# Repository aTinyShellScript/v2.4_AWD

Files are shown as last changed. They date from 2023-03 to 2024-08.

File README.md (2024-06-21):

# WTF Is This?

An AWD Mod for the Voron v2.4.

## Getting Started

Take a look at the [Sourcing](https://docs.atinyshellscript.com/sourcing/) page to see what you need.

## Issues

Best to report issues directly to @aTinyShellScript in the Armchair Heavy Industries discord. You can also open a GitHub issue here.

## Mods

Put your mod in it's own folder under /UserMods, include a readme.md, and submit a PR.

## Website

Documentation and Assembly Info has been moved to: https://docs.atinyshellscript.com/

## Thanks

[KayosMaker](https://github.com/KayosMaker) whose idea for printed aligners I have shameless borrowed.

[scheini79](https://github.com/scheini79) who made the DoubleT Pin mid-body STL.

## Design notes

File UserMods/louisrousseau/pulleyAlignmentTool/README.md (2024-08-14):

# Pulley Alignment Tool

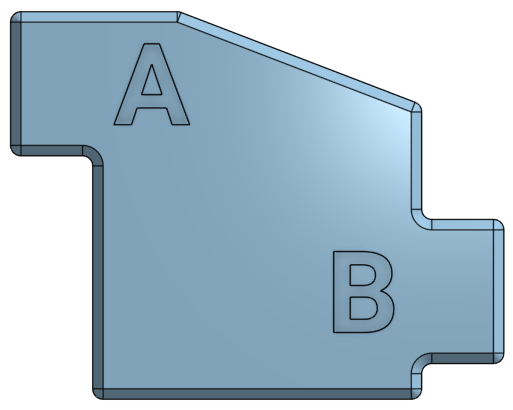
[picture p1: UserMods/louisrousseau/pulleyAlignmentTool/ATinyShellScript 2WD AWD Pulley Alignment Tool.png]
Pulley Alignment Tool


The GT20 pulley height adjustment on the A/B stepper shafts doesn't match the Voron tool or manual diagrams which are referenced on the stepper housing and stock printed motor mounts.

This little tool lets you align the toothed pulleys on your A/B steppers using the face touching the extrusions; doing it this way works around any differences in metal plate thickness.

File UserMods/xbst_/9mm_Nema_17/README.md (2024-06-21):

# AWD 9mm Nema 17 Voron 2.4 Mod
I heard you like mods. So I made a mod of [Chairman Meow's 9mm mod](https://github.com/aTinyShellScript/v2.4_AWD/tree/printy_9mm_mod/Mods/NEMA17_9mm_Belts) of [ATSS's AWD V2.4 mod](https://github.com/aTinyShellScript/v2.4_AWD).

## Picture

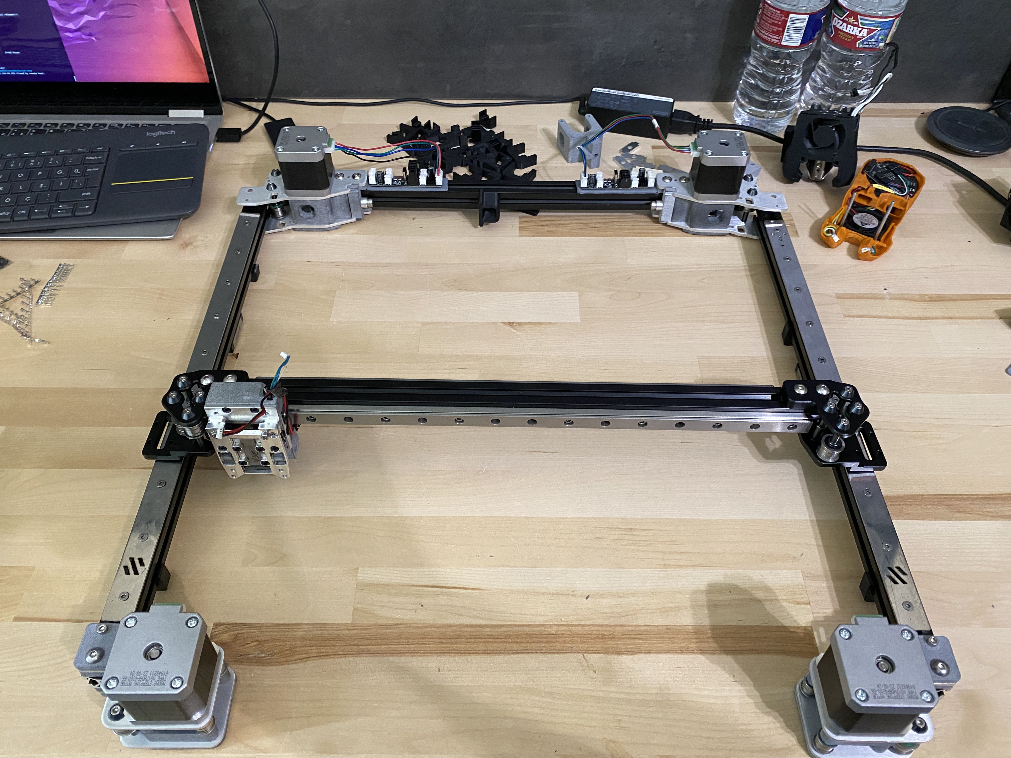
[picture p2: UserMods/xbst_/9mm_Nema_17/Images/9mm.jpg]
AWD 9mm Nema 17 Voron 2.4 Mod on my V2.4


## YT Video

AWD 9mm Nema 17 Voron 2.4 Mod (https://www.youtube.com/watch?v=yxPKsFqpcdE)

## BOM

**For Aluminium DXFs: [SendCutSend](https://sendcutsend.com/).** Make sure to order the 2x tensioner plates from this mod and 4x each of the front and rear plates from the main mod. Alternatively, you can buy [this](https://west3d.com/products/voron-v2-4-awd-mod-by-atinyshellscript-kit-by-west3d-nema17-and-nema14-4-motor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) set from West3D and try using the [printed tensioner blocks](https://github.com/xbst/v2.4_AWD/tree/main/UserMods/xbst_/9mm_Nema_17/STL/OPTIONAL-Tensioner-x2.stl) (might not work as well as aluminium ones).

**Table below does not include parts needed for XY joints (+8x F695 & +4x 695 & more M5 shims) and some fasteners.**

|Part |Qty|China|US Source|
|---|---|-----|---|
|Long Shaft Nema17s |4  |[Aliexpress](https://s.click.aliexpress.com/e/_DmJ14C5) or [Magic Phoenix](https://magicphoenix.xyz/product/moons-ms17hd6p4200/)|-|
|20T 10mm Pulleys |4  |[Aliexpress](https://s.click.aliexpress.com/e/_DEDj1Jn)|[West3D](https://west3d.com/products/pulleys-and-idlers-gt2-20t-gt2-16t?variant=41970925863124)|
|9mm GT2 Belts  |Depends|[Aliexpress](https://s.click.aliexpress.com/e/_DBHesYl)|[West3D](https://west3d.com/products/gates-gt2-open-belt-ll-2gt-9-9mm-wide-voron-v0-v1-v2-switchwire) or [Fabreeko](https://www.fabreeko.com/products/gates-gt2-open-belt-ll-2gt-6-9-12-reinforced?variant=42466462761215)|
|DoubleT Pins (30mm)|6  |[Aliexpress](https://s.click.aliexpress.com/e/_DloOKWp)|[Fabreeko](https://www.fabreeko.com/products/9mm-cnc-pins-washers-by-double-t-honeybadger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)|
|F695 Bearings |20 |[Aliexpress](https://s.click.aliexpress.com/e/_DnqTqXF)|[Amazon](https://amzn.to/3SUwVGT) or [West3D](https://west3d.com/products/berserker-f695-2rs-abec9-grade-bearings-hybrid-ceramic-bearings-sf625c-2rs)|
|695 Bearings |8  |[Aliexpress](https://s.click.aliexpress.com/e/_Dki64Av)|[Amazon](https://amzn.to/3wojx63) or [West3D](https://west3d.com/products/695-2rs-bearings-non-flanged)|
|F623 Bearings |12 |[Aliexpress](https://s.click.aliexpress.com/e/_DlwHNjr)|[Amazon](https://amzn.to/49QJBVS) or [West3D](https://west3d.com/products/berserker-f623-2rs-abec9-grade-bearings-hybrid-ceramic-bearings-sf623c-2rs)|
|SMR103 Bearings |6  |[Aliexpress](https://s.click.aliexpress.com/e/_DlnA6Rj)|[Amazon](https://amzn.to/3PlBjOf)|
|10x5x1 Shim |?  |[Aliexpress](https://s.click.aliexpress.com/e/_Dmrs6wv)|-|
|6x3x0.5 Shim |?  |[Aliexpress](https://s.click.aliexpress.com/e/_Dmrs6wv)|-|
|M3x45mm Screws |16 |[Aliexpress](https://s.click.aliexpress.com/e/_DBwrZQ9)|[Amazon](https://amzn.to/3IjOWcs)|

I used these XY joints from Funssor (includes ZZ bearings): [Aliexpress](https://s.click.aliexpress.com/e/_DDTiurF)

You can print the plastic parts in ABS on your FDM printer. I didn't have a working printer at the time, so I ordered them printed in MJF from [JawsTec](https://www.jawstec.com/3d-printing-service/?aff=6).

Like ATSS's mod, does not include mounts for drag chains or Y limit switches.

Aliexpress, Jawstec Affiliate and Amazon Associate links above. I earn a commission on qualifying purchases at no extra cost to you.

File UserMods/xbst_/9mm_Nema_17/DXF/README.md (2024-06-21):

## Use the Nema 17 Front/Rear plates from the [main mod](../../../../DXFs/NEMA17).

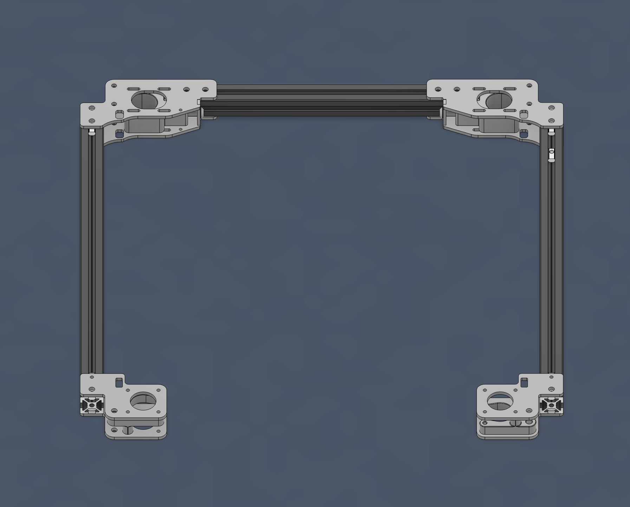
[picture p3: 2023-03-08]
Images/Gantry.png

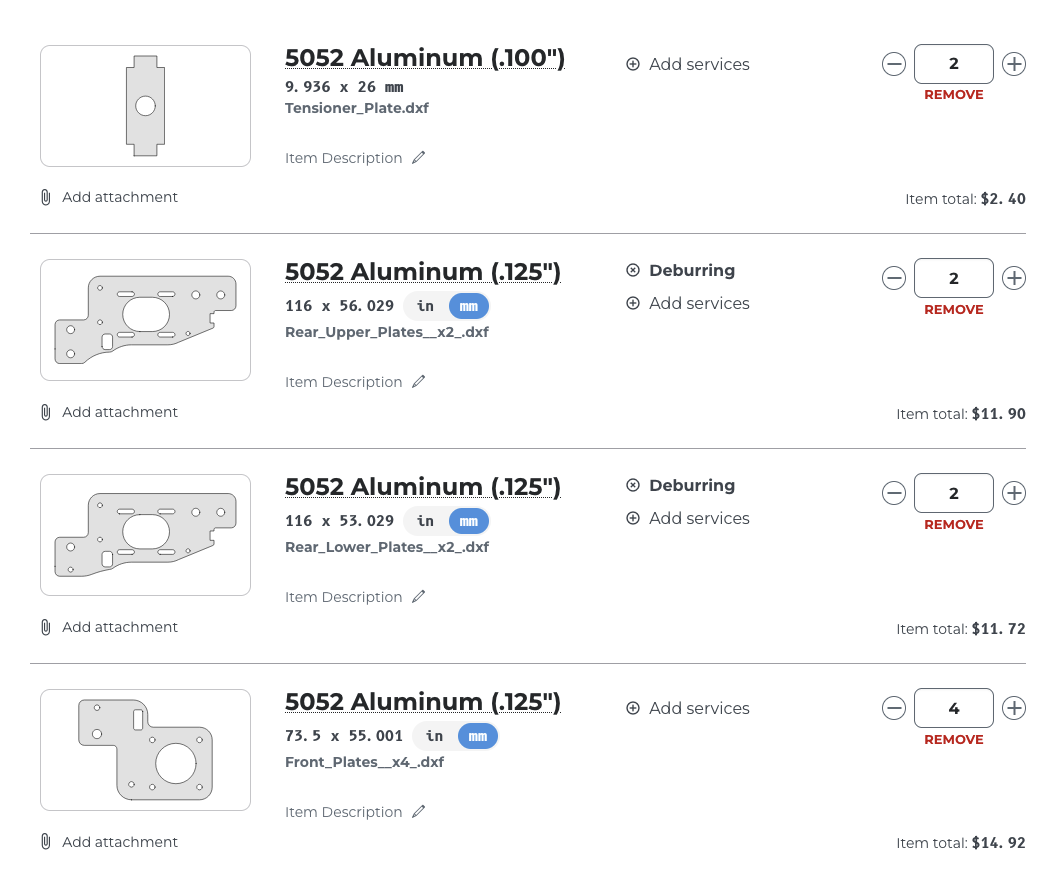
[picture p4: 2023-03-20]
Images/SCScart.png

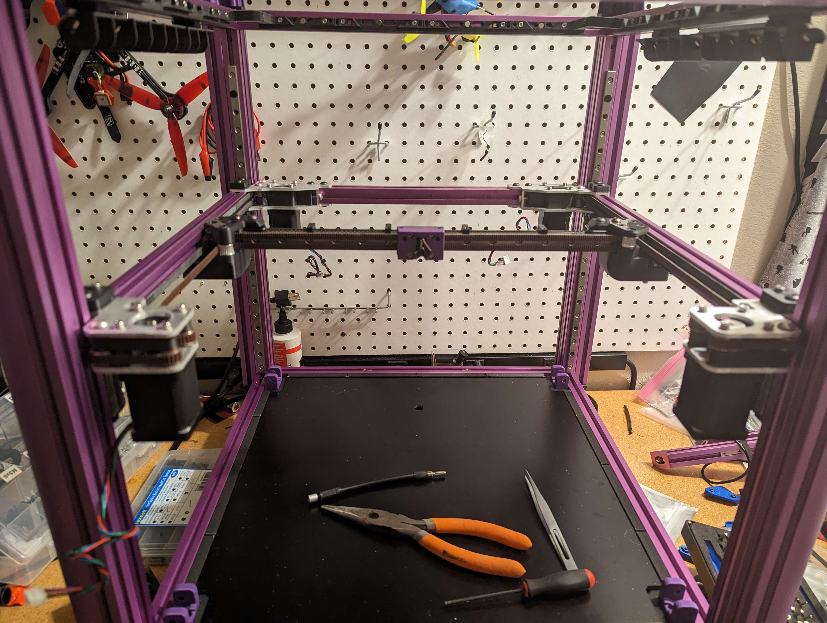
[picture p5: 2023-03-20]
Images/Belted_v1.jpg

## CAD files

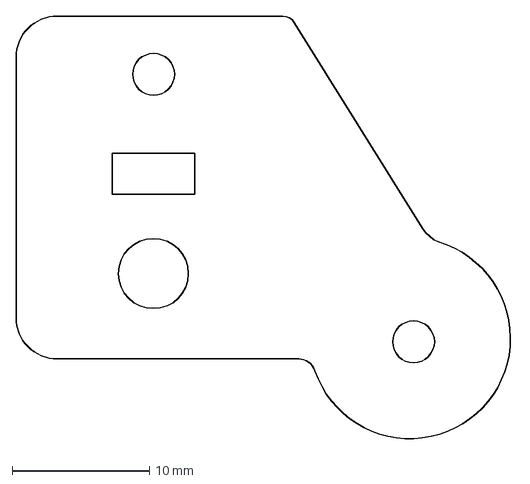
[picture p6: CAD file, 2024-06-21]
DXFs/FrontSimpleIdler_[x4].dxf
36.3 x 31.2 mm

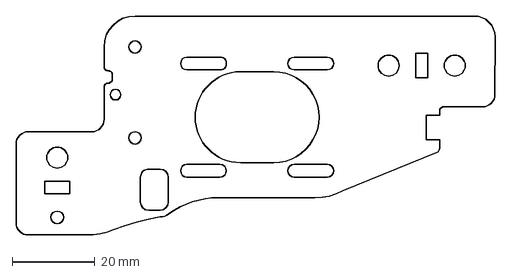
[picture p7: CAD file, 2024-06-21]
DXFs/NEMA14/14_RearPlate_[x4].dxf
116.0 x 53.0 mm

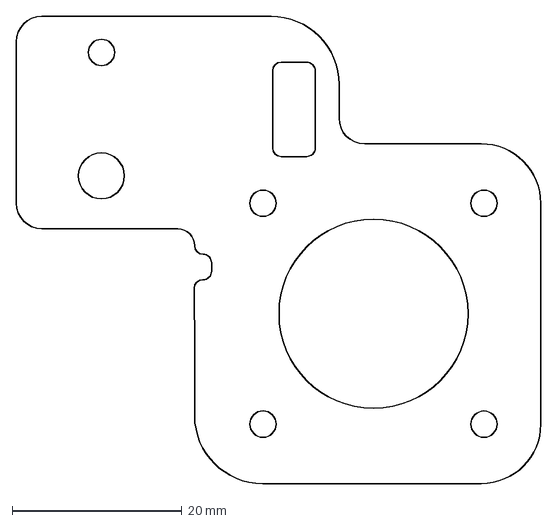
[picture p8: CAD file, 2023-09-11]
DXFs/NEMA14/Alternate/EURO_14_FrontPlate_[x4].dxf
61.8 x 55.0 mm

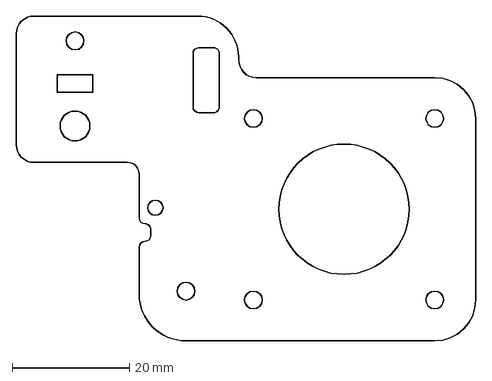
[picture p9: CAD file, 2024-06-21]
DXFs/NEMA17/17_FrontPlate_[x4].dxf
78.5 x 55.5 mm

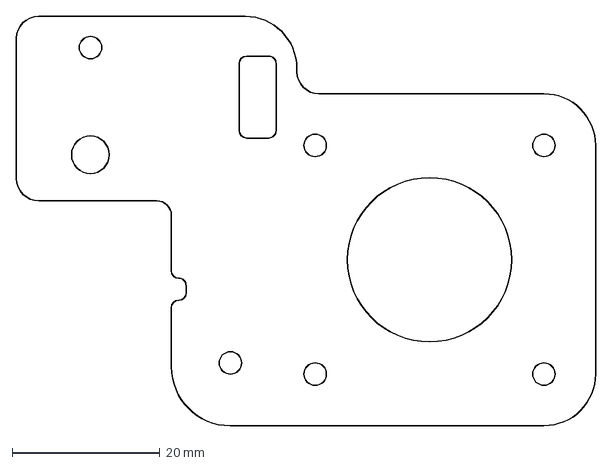
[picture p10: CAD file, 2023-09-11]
DXFs/NEMA17/Alternate/EURO_17_FrontPlate_[x4].dxf
78.5 x 55.5 mm

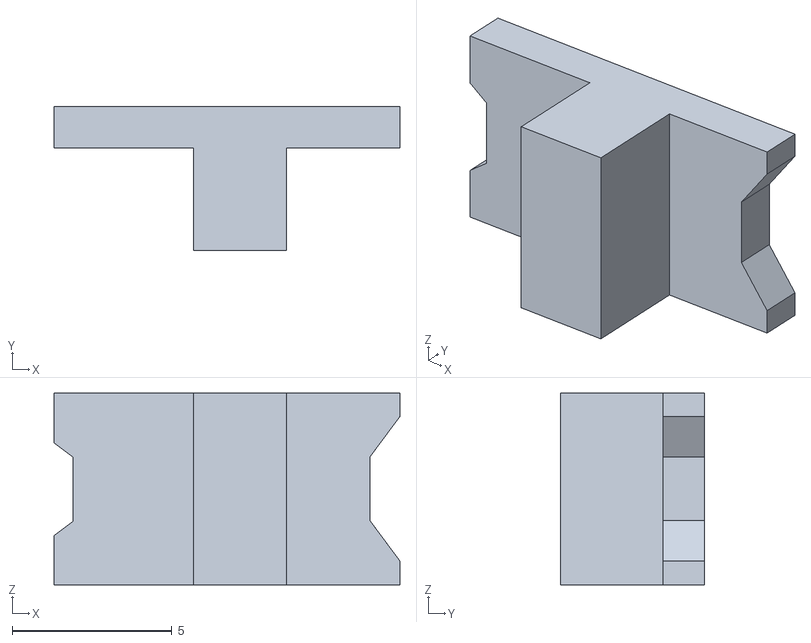
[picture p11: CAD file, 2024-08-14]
STLs/NEMA14/MetalPlates/M5_M3_Aligner_[x8].stl
10.8 x 4.50 x 6.00

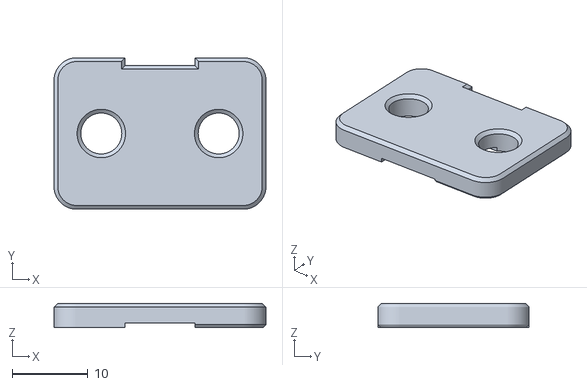
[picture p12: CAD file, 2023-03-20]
STLs/NEMA14/MetalPlates/v1 Plates/Rear_Top_Clamp_[x2].stl
28.0 x 20.0 x 3.20

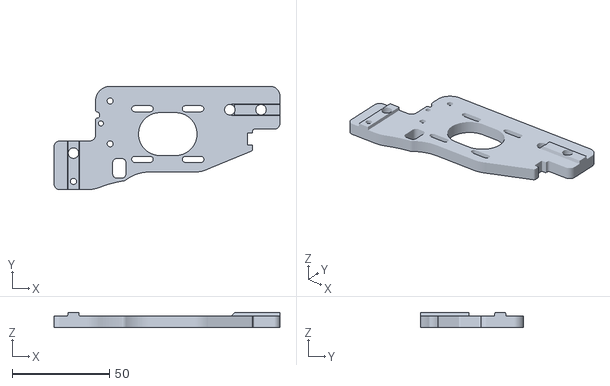
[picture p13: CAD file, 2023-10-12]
STLs/NEMA14/Printed/14_RearDrive_B_[x2].stl
116.0 x 53.0 x 7.70

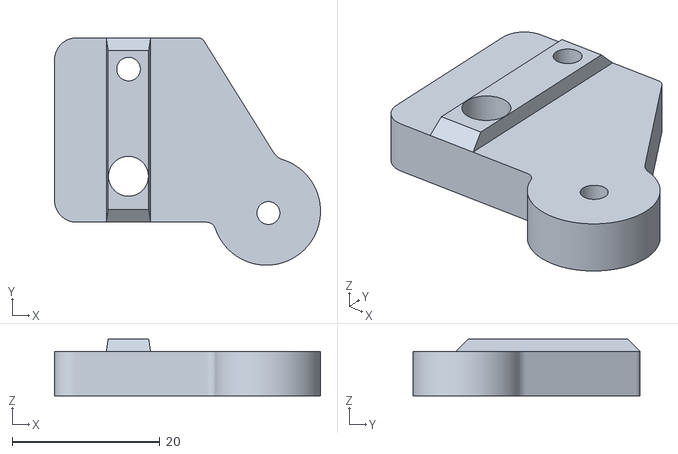
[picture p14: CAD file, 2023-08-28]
STLs/NEMA14/Printed/SimpleIdlers/SimpleIdler_x2.stl
36.1 x 30.8 x 7.70

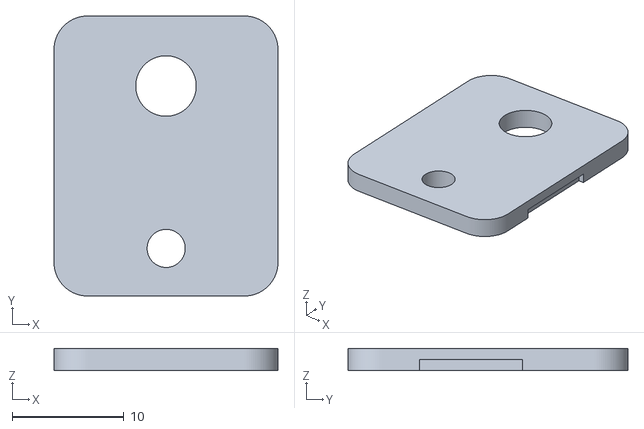
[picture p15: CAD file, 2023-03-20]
STLs/NEMA17/MetalPlates/v1 Plates/Rear_Bottom_Clamp_Grip_[x2].stl
20.0 x 25.0 x 2.00

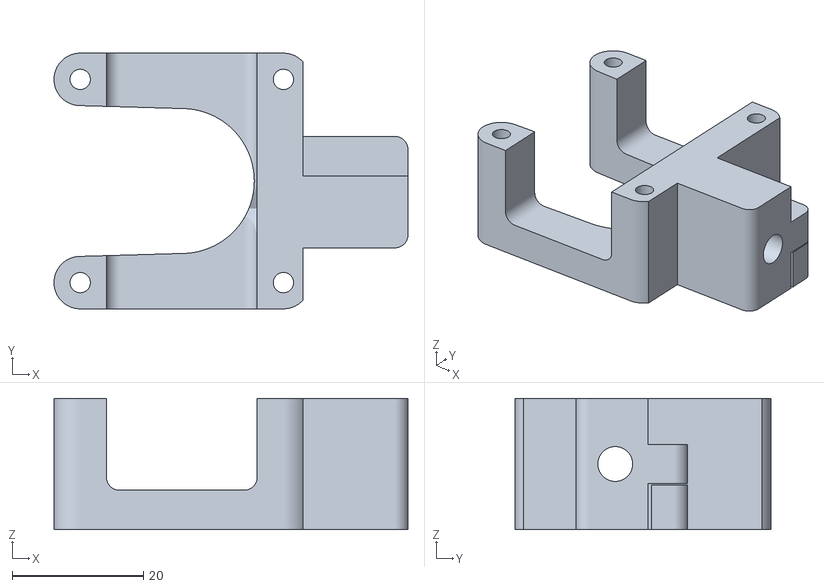
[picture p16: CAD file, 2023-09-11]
STLs/NEMA17/Printed/17_RearTensioner_AWD_Supported_x2.stl
54.0 x 39.0 x 20.0

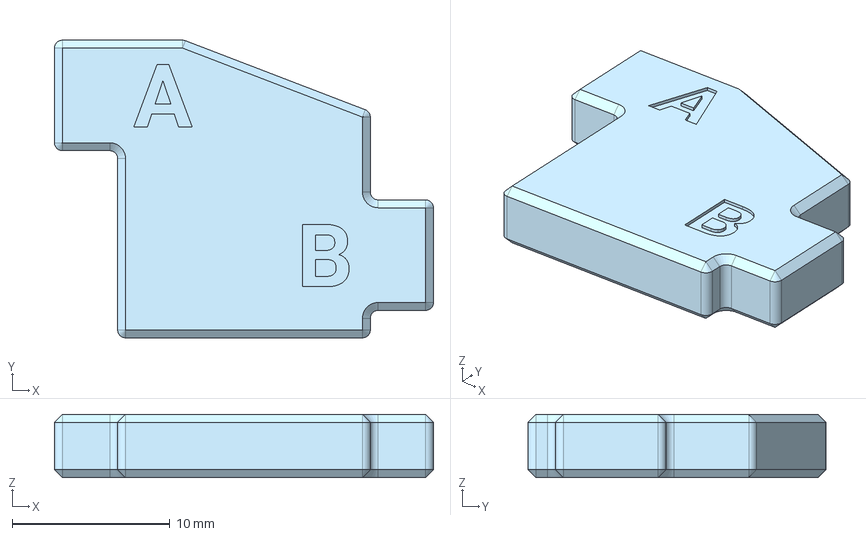
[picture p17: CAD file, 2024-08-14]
UserMods/louisrousseau/pulleyAlignmentTool/ATinyShellScript 2WD AWD Pulley Alignment Tool.step
24.0 x 18.8 x 4.00 mm

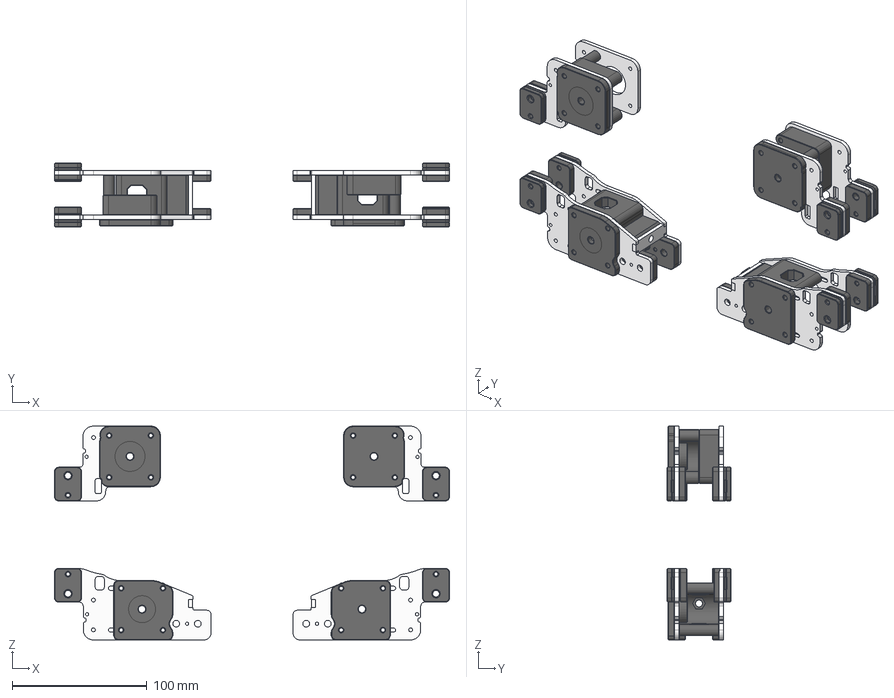
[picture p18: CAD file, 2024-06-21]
UserMods/xbst_/9mm_Nema_17/CAD/CAD.step
292.9 x 47.2 x 158.6 mm
Rear-Plate x 4
10mm-Tensioner x 2
Rear-Extrusion-Spacer x 4
Side-Extrusion-Spacer x 8
Z-Belt-Grip x 8
Z-Belt-Clamp x 8
Rear-Motor-Spacer x 2
Rear-Left-Shaft-Support
Rear-Right-Shaft-Support
Front-Plate x 4
Front-Left-Shaft-Support
Front-Motor-Spacer x 2
Front-Right-Shaft-Support

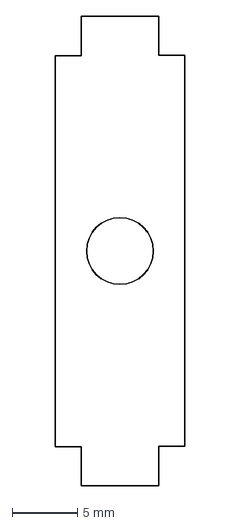
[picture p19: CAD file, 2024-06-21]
UserMods/xbst_/9mm_Nema_17/DXF/Tensioner_Plate_x2.dxf
9.94 x 36.0 mm

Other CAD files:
STLs/NEMA17/Printed/SimpleIdlers/SimpleIdler_x2.stl
UserMods/xbst_/9mm_Nema_17/STL/OPTIONAL-Tensioner-x2.stl
DXFs/NEMA14/14_FrontPlate_[x4].dxf
DXFs/NEMA14/Alternate/EURO_14_RearPlate_[x4].dxf
DXFs/NEMA17/17_RearPlate_[x4].dxf
DXFs/NEMA17/Alternate/EURO_17_RearPlate_[x4].dxf
DXFs/Rear_Plates_[x4].dxf
DXFs/Tensioner_Plates_[x2].dxf
STLs/NEMA14/MetalPlates/10mmSpacer_[x2].stl
STLs/NEMA14/MetalPlates/14_FrontMidBody_[x2].stl
STLs/NEMA14/MetalPlates/14_RearTensioners_Supported_[x2].stl
STLs/NEMA14/MetalPlates/Dual_M5_Aligner_[x4].stl
STLs/NEMA14/MetalPlates/Front_Clamp_Grip_[x4].stl
STLs/NEMA14/MetalPlates/Front_Clamp_[x4].stl
STLs/NEMA14/MetalPlates/v1 Plates/Rear_Bottom_Clamp_[x2].stl
STLs/NEMA14/MetalPlates/v1 Plates/Rear_Top_Clamp_Grip_[x2].stl
STLs/NEMA14/Printed/14_Front_Plate_Mirrored_[x1].stl
STLs/NEMA14/Printed/14_Front_Plate_Spacer_Mirrored_[x1].stl
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

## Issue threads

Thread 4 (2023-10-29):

Add 2WD to Cad

madmaximus00, 2023-10-29:
Would it be possible to add the 2WD config to the CAD?

aTinyShellScript, 2023-10-31:
@madmaximus00 I have a CAD rework coming to make things easier and it will include 2WD.

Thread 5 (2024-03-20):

NEMA17 Printed Part not fit

ghost, 2024-03-20:
I printed the 17_FrontPlate_x2.stl part, but it doesn't fit the extruder.
Can you fix this?

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

aTinyShellScript, 2024-10-02:
I got lazy with the printed parts and used measurements from pieces of extrusion I had lying around. They were a best-effort for someone who asked and aren't really a supported part of the mod. You can edit the profile in the CAD to fit.

Closed 2024-10-02.

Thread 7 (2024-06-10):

2WD needs 4x printed 10mm spacers, not 2x

louisrousseau, 2024-06-10:
Documentation should have a note to this effect

aTinyShellScript, 2024-06-10:
There is a breaking issue with the build pipeline for the docs right now, so this will be updated at some point in the near future.

aTinyShellScript, 2024-06-21:
Docs site has been updated.

https://docs.atinyshellscript.com/v2.4/2wd/#printed-parts

Closed 2024-06-21.

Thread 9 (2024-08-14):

M5_M3_Aligner_[x8].stl wrong size ?

ga73, 2024-08-14:
Hi,
the file STLs/NEMA14/MetalPlates/M5_M3_Aligner_[x8].stl
the part scale seems way off , it's HUGE.
can this be corrected please ?

thanks!

aTinyShellScript, 2024-08-14:
@ga73 Good catch. It looks like I selected 'cm' instead of 'mm' when fixing the part alignment after export. Should be fixed now.

Closed 2024-08-14.

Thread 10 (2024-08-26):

F695 nema 14 steel plates cad/info conflict?

ga73, 2024-08-26:
Hi,

The diagrams on the site mention a F695 bearing required on the front (steel plate) parts but the cad doesnt mention this at all ??

is a F695 bearing stack required on the front (as well as the 3 x F623 bearing stacks) or just the 3xstacks of F623 ?

thanks!!

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
ga73, 2024-08-26:
** @abdulhkeemGit ** virus links....really?? grow up!!

can anyone give actual help...thanks!

xPakrikx, 2024-09-06:
Looks like F695 is required not F623. maybe mistake in cad.

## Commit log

2023-03-12 Adjusted Hole Size
    Slightly enlarged holes for the printed parts.
    [Front_MidBody_[x2].stl, Rear_TensionerBody_[x2].stl]
2023-03-12 STL updates
    Changed tensioner to use M5 nut.
    [Front_MidBody_[x2].stl, Rear_TensionerBody_[x2].stl]
2023-03-12 Rotate STLs Correctly
    [Front_MidBody_[x2].stl, Rear_TensionerBody_[x2].stl]
2023-03-20 Updates after initial plate cuts
    Only screwed up a few things.
    - Created a bottom rear plate, as it needs to be a few mm shorter.
    - Moved front stepper forward 2mm.
    - Changed M5 tapped holes to m3 to utilize m3x20mm standoffs.
    - Updated BOM and images
    [Front_Plates_[x4].dxf, Rear_Lower_Plates_[x2].dxf, Rear_TensionerBody_[x2].stl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]
2023-03-20 Z Belt Clamps
    Added clamp stls
    [Front_Clamp_Grip_[x4].stl, Front_Clamp_[x4].stl, Rear_Bottom_Clamp_Grip_[x2].stl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]
2023-04-22 RMRRF Version
    Parts As Seen on the DoomCube at RMRRF.
    [Front_Lower_Plates_[x2].dxf, Front_Upper_Plates_[x2].dxf, Rear_Lower_Plates_[x2].dxf]
2023-04-30 NEMA17 Test Parts
    STLs for verifying fitment of NEMA17 bits.
    [17_FrontMidBody.stl, 17_FrontPlates.stl, 17_RearLowerPlate.stl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]
2023-04-30 NEMA17 Fixes and DXFs
    Fixed hole spacing for NEMA rear plates. Fixed rear tensioner for same issue. Added DXFs for NEMA17 AWD and a Dummy Front Idlers to allow the RearPlates to be used in a normal 2 stepper system.
    [17_FrontPlate_[x4].dxf, 17_RearLowerPlate.stl, 17_RearLowerPlate_[x2].dxf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]
2023-04-30 Rearrangement of files
    Moved NEMA14 and NEMA17 files into specific folders. Left common files in the root of DXF or STL.
    [FrontDummyIdler_[x4].dxf, Front_Lower_Plates_[x2].dxf, Front_MidBody_[x2].stl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]
2023-04-30 NEMA17 Printed
    Experimental printable NEMA17 setup. Currently Untested.
    [17_FrontPlateSpacer_Printed.stl, 17_FrontPlate_Printed.stl, 17_FrontPlates.stl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]
2023-05-04 Printed Part Fixes
    Slightly enlarged some holes and created larger indexing tabs
    [17_FrontPlateSpacer_Printed.stl, 17_FrontPlate_Printed.stl, 17_FrontSimpleIdler.stl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]
2023-05-05 NEMA14 Printable
    Printable NEMA14 parts, why not?
    [FrontPlateSpacer_Printable.stl, FrontPlate_Printable.stl, RearLowerPlate_Printable.stl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]
2023-05-05 CAD Update
    STEP file with all NEMA14/NEMA17 laser cut and printable parts.
    [2.4_AWD_NEMA14 v3.step]
2023-05-05 STL Reorganization
    [14_FrontMidBody_x2.stl, 14_FrontPlateSpacer_x2.stl, 14_FrontPlate_x2.stl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]
2023-05-05 Simple Printed Tension Plates
    [14_TensionerPlate_x2.stl, 17_TensionerPlate_x2.stl, SimpleIdler_Spacer_x2.stl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]
2023-07-04 File Reorg
    [14_FrontMidBody_[x2].stl, 14_FrontPlateSpacer_x2.stl, 14_FrontPlate_[x4].dxf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]
2023-07-05 CAD Update and Added Spacer
    [10mmSpacer_[x2].stl]
2023-07-28 CAD Update
    Added Bearing Idlers to CAD
2023-07-28 CAD Readability Update
    Split the NEMA14/17 and LaserCut/Printed CAD into their own assemblies.
2023-07-31 CAD Update
    Steppers and Pulleys added
2023-07-31 Belt Path to CAD
    NEMA14 LaserCut CAD now has a terrible example of the belt path.
2023-08-03 Experimental Front Mount
    Not-yet-tested space savings for only the 14 front mount.
    [14_FrontMidBody_[x2].stl, 14_FrontPlate_[x4].dxf]
2023-08-14 Fixing incorrect naming of STLs.
    [17_RearTensioner_2WD_x2.stl, 17_RearTensioner_AWD_x2.stl]
2023-08-14 Fixed plate positioning error
    The top and bottom A drive plates on the NEMA17 model were transposed.
2023-08-28 Printed N14 and Simple Idler Update
    Fixed extrusion indexing bit on the simple idlers and N14 printables. Updated CAD. Nema17 needs to be rebuilt because I suck at CAD.
    [14_FrontPlateSpacer_x2.stl, 14_FrontPlate_x2.stl, 14_RearLowerPlate_A_x1.stl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]
2023-08-28 non-smol CAD update
    Updating CAD to keep the version numbers in line.
2023-08-29 Rear Plate Rework
    DXFs plus CAD changes
    [14_RearLowerPlate_[x2].dxf, 14_RearPlate_[x4].dxf, 14_RearUpperPlate_[x2].dxf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]
2023-08-29 STL quantity changes
    [Rear_Clamp_Grip_[x4].stl, Rear_Clamp_[x4].stl, Rear_Top_Clamp_Grip_[x2].stl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]
2023-08-30 Increased tensioner plate depth to 3.2mm
    Seeing some slight bending from user builds. Not bad but increasing to 3.2mm should help.
    [14_RearPlate_[x4].dxf, 17_RearPlate_[x4].dxf]
2023-08-31 Restoring some files
    These are still needed for anyone with v1 plates.
    [Rear_Bottom_Clamp_Grip_[x2].stl, Rear_Bottom_Clamp_[x2].stl, Rear_Top_Clamp_Grip_[x2].stl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]
2023-09-11 PreSupported STLs & Euro Friendly DXFs
    LaserBoost won't cut sub-3mm holes.
    [14_RearTensioner_A_[x1].stl, 14_RearTensioner_B_[x1].stl, 14_RearTensioners_Supported_[x2].stl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]
2023-09-15 Fixed N14 tensioners
    Last update removed the M5 nut hole.
    [14_RearTensioner_A_x1.stl, 14_RearTensioner_B_x1.stl, 14_RearTensioners_Supported_[x2].stl]
2023-09-26 Fixed Rear Plates and Updated Fronts
    [14_FrontPlateSpacer_x2.stl, 14_FrontPlate_x2.stl, 14_Front_Plate_Mirrored_[x1].stl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]
2023-09-26 Actually fixed rear plates
    I swear, this time.
    [14_RearDrive_A_[x2].stl, 14_RearDrive_B_[x2].stl]
2024-02-27 STLs, CAD & DXF
    [CAD.step, Front-Left-Shaft-Support-x1.stl, Front-Motor-Spacer-x2.stl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]
2024-06-21 v3 Update
    Added optional printed aligners to assist with assembly.
    [14_FrontPlate_[x4].dxf, 14_RearPlate_[x4].dxf, 17_FrontMidBody_DoubleT_Pin_Alternate_x2.stl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]
2024-07-07 Added Pulley Alignment Tool UserMod - Initial commit
    [ATinyShellScript 2WD AWD Pulley Alignment Tool.step, ATinyShellScript 2WD AWD Pulley Alignment Tool.stl]
2024-08-14 Fixed scale of Aligner STL
    Messed up the scale when adjusting alignment. Fixes Issue #9
    [M5_M3_Aligner_[x8].stl]
